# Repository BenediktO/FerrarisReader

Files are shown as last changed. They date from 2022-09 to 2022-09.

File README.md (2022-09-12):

# Ferraris Reader

This repo contains the files of the FerrarisReader project - A tool to read back power consumption of an old-school Ferraris meter.

## Physical setup

The sensor consists of an IR LED and a matching IR fototransistor or fotodiode, mounted such that the red marking on the turning wheel reduce the transmitted light effectively.
A holding structure is provided in `Objects/FerrarisHolder.stl` ready to slice.
It is designed to hold a 5mm LED and a 3mm fototransistor.
Edit `Objects/FerrarisHolder.scad` to fit the design to your need and use [openscad](https://openscad.org/) to convert to a slice-able file.
It is designed such that the point where the reflection occurs in a distance of 9mm. This can be changed by modifiying the distance between LED and sensor.
The schematic is shown below:

schematic

You only need the LED, sensor pair, a few resistors and a transistor (which is not really needed) together with an Arduino.
The Arduino needs to have a Serial interface, native or not or via FTDI does not really matter. You might, however need to change the Serial Port.
One pin of the arduino is reserved for the IR LED(s), in case you have more than one meter you want to read out, simply connect more IR LEDs in serial or parallel to the transistor. If you connect them in series, you need to lower the resistor value.
If you use a fotodiode instead of a fototransistor, you might need to increase the resistor to account for the reduced current.

Put the LED and the sensor into the 3D printed holder and connect wires to each of the pins.
On the other end of the wires create the above-shown circuit, test the LED polarity using a multimeter in diode-mode and the photo sensor in resistor mode.

In case you want some visual feedback, connect an LED to a spare pin using an appropriate resistor.
You can also use the builtin LED (13).

## Arduino sketch

You might need to modify the Arduino sketch.

- Specify the IR LED pin, there is only one even though many sensors are connected.
- Specify the number of sensors
- Specify their pin numbers. Important: All those have to be analog pins (`A0`, `A1`, ...)
- Optional: Specify the pins of the activity LED

## Experimenting with the settings

Connect the sensor(s) to the meter by using a bit of tape. Make sure that the sensor is properly aligned.
This can be done by enabling `ALIGNMENT_MODE` in the Arduino Sketch and observing the results in the serial monitor or serial plotter.
The dips in reflectivity should be as clearly visible as possible.

## SCPI Interface

The device follows the SCPI standard, a well-established text-based protocol to communicate with laboratory equipment.

The following commands are supported:

- `*IDN?`: returns the identification string
- `*RST`: resets the device
- `MEASure`
  - `:TICKs`
    - `?`: returns the number of ticks received
    - `:SET [CHANNEL = 0,]<VALUE>`: used to preset the tick counter
    - `:PERiod? [CHANNEL = 0]`: returns the revolution time of the last turn
    - `:LAST? [CHANNEL = 0]`: returns the time since the last tick
  - `:SENSor`
    - `:DARK? [CHANNEL = 0]`: returns the dark current (IR LED off)
    - `:ACTIve? [CHANNEL = 0]`: returns the active current (IR LED on)
    - `:EFFEctive? [CHANNEL = 0]`: returns the difference active - dark current
    - `:SNR? [CHANNEL = 0]`: returns a quantity from 0 - 1, representing the quality, 1 is best.

- `CALCulate`
  - `:ENERgy? [CHANNEL = 0]`: returns the calculated energy
  - `:POWer? [CHANNEL = 0]`: returns the calculated power, which is the average power of the last revolution

- `CONFigure`
  - `:SENSor`
    - `:THREshold`
      - `:UPPer [CHANNEL = 0,]<THRESHOLD>`: sets the upper threshold of a channel
      - `:UPPer? [CHANNEL = 0]`: returns the upper threshold of a channel
      - `:LOWer [CHANNEL = 0,]<THRESHOLD>`: sets the lower threshold of a channel
      - `:LOWer? [CHANNEL = 0]`: returns the lower threshold of a channel
    - `:DURation [CHANNEL = 0,]<DURATION>`: sets the minimum duration of the pulse
    - `:DURation? [CHANNEL = 0]`: returns the minimum duration of the pulse

- `SYSTem`
  - `:CHANnels?`: returns the number of channels of the device
  - `:FREQuency?`: returns the sampling frequency of the last second

Explanation:

This tree represents all possible commands. To assemble a command, join the strings on the branches.
I.e. to set the upper threshold of sensor 1 to 200, use:

`CONFigure:SENSor:THREshold:UPPer 1,200`

The upper case parts of the tokens are required, the lower case part can be omitted.
Note that the command is case-insensitive.
The following commands are equivalent:

```SCPI
CONFigure:SENSor:THREshold:UPPer 1,200
CONF:SENS:THRE:UPP 1,200
conf:sens:thre:upp 1,200
```

Values in brackets `[]` are optional, the default for `CHANNEL` is always 0.
Values in `<>` are required. Parameters are separated by `,`, commands can be joined using `;`.
Queries which return an answer are terminated with a `?`.

## Python scripts

### logger.py

To read back the data from a PC or raspberry, use the provided python script.
It needs the additional package `pyserial`, which can be installed using pip.
Use `python3 logger.py --help` for a reference how to use the program.

### plot.py

To plot the captured data, the script `analyze/plot.py` can be used.
It needs the additional packages `numpy` and `matplotlib`.
Use `python3 plot.py --help` for a reference how to use the program.

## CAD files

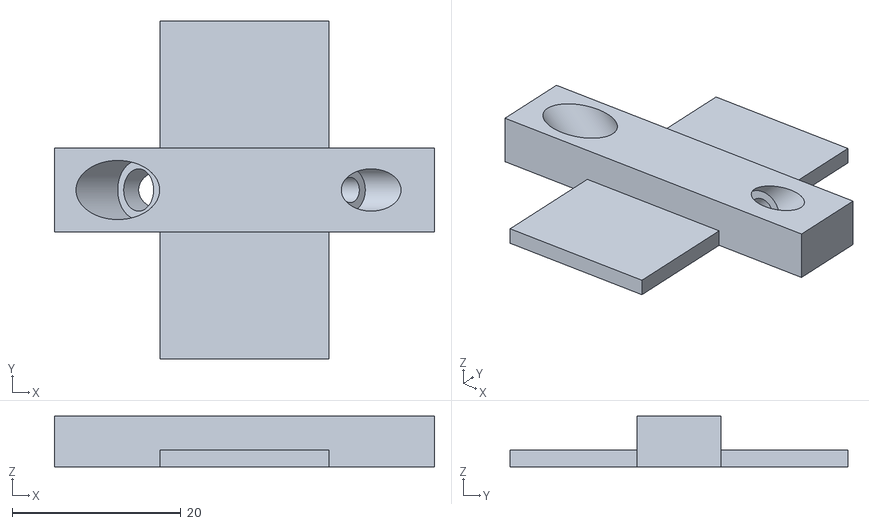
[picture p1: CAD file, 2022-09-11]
Objects/FerrarisHolder.stl
45.0 x 40.0 x 6.00

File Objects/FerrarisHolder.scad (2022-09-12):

$fn = 100;

LED_DIAMETER = 5;       // in mm
SENSOR_DIAMETER = 3;    // in mm
SENSOR_DISTANCE = 18;   // in mm

LENGTH = 45;            // in mm
WIDTH = 10;             // in mm
HEIGHT = 6;             // in mm

difference() {
    union() {
        translate([-LENGTH / 2, -WIDTH / 2])
            cube([LENGTH, WIDTH, HEIGHT]);
        translate([-10, -20])
            cube([20, 40, 2]);
    }
    translate([SENSOR_DISTANCE / 2, 0])
        rotate([0, 45, 0])
        union(){
            translate([0, 0, -100])
                cylinder(h=200, r=SENSOR_DIAMETER / 2);  // IR fototransistor
            translate([0, 0, 5])
                cylinder(h=100, r=SENSOR_DIAMETER / 2 + 1);
        }

    translate([-SENSOR_DISTANCE / 2, 0])
        rotate([0, -45, 0])
        union(){
            translate([0, 0, -100])
                cylinder(h=200, r=LED_DIAMETER / 2);  // IR fototransistor
            translate([0, 0, 5])
                cylinder(h=100, r=LED_DIAMETER / 2 + 1);
        }
}

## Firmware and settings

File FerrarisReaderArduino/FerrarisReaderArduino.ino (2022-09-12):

// FerrarisReader - A tool to read old school ferraris energy meters
//
// Copyright (C) 2022  Benedikt Otto <otto@hiskp.uni-bonn.de>
//
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


#include "Arduino.h"

#include <ctype.h>

#include "Vrekrer_scpi_parser.h"

//#define DEBUG

SCPI_Parser controller;


// Serial port to use
#define SERIAL Serial

// Number of sensors
#define NUM_CHANNELS 2

// Pin where the LED (via transistor) is connected to
#define IR_LEDS 9
// Pins for the sensors
int IR_SENSORS[NUM_CHANNELS] = {A0, A1};

// Pin where the activity LED is connected to, comment to deactivate
#define ACTIVITY_LED_PIN 10

// default values
#define DEFAULT_UPPER_THRESHOLD 100
#define DEFAULT_LOWER_THRESHOLD 50
#define DEFAULT_DURATION 20

// meter setup
#define TURNS_PER_KWH 75
#define KWH_PER_TURN (1.0 / TURNS_PER_KWH)

// target samplingrate
#define SAMPLINGRATE 250

// For aligning the sensor, uncomment the following line:
//#define ALIGNMENT_MODE



// Do not touch

#ifdef ALIGNMENT_MODE
  #define ALIGNMENT_PIN A0
#endif


#ifdef ACTIVITY_LED_PIN
  #define ACTIVITY_LED_ON digitalWrite(ACTIVITY_LED_PIN, HIGH);
  #define ACTIVITY_LED_OFF digitalWrite(ACTIVITY_LED_PIN, LOW);
#else
  #define ACTIVITY_LED_ON
  #define ACTIVITY_LED_OFF
#endif


bool readout_state = false;
uint8_t second_counter = 0;
uint16_t livetime_counter = 0;
uint16_t livetime_counter_buf = 0;

unsigned long time;
unsigned long last_time;
unsigned long last_time_seconds;


// structure holding the sensor data and parameters
struct SensorData
{
  uint16_t active_value;
  uint16_t dark_value;
  int high_counter;
  int low_counter;
  bool state;
  uint32_t ticks;
  uint32_t last_tick;
  uint32_t second_last_tick;
  uint16_t upper_threshold;
  uint16_t lower_threshold;
  uint16_t duration;
};


struct SensorData sensors[NUM_CHANNELS];


////////////////////////////////////////////////////////////////////////////////
//                                   tools                                    //
////////////////////////////////////////////////////////////////////////////////


// Extracts the channel number from the SCPI parameters, channel is always the first
int get_channel_number(SCPI_P parameters) {
  if (parameters.Size() < 1)
    return 0;
  int temp = String(parameters[0]).toInt();
  // basic validation
  if ((0 <= temp) && (temp < NUM_CHANNELS))
    return temp;
  return 0;
}

// Reset all sensor structs
void reset(void) {
  struct SensorData * sensor;
  for (int i=0; i<NUM_CHANNELS; i++) {
    sensor = &sensors[i];
    sensor->ticks = 0;
    sensor->high_counter = 0;
    sensor->low_counter = 0;
    sensor->state = true;
    sensor->upper_threshold = DEFAULT_UPPER_THRESHOLD;
    sensor->lower_threshold = DEFAULT_LOWER_THRESHOLD;
    sensor->duration = DEFAULT_DURATION;
  }
}

// Returns char array with lower case
char *toLower(char *str, size_t len)
{
    char *str_l = calloc(len + 1, sizeof(char));

    for (size_t i = 0; i < len; ++i) {
        str_l[i] = tolower((unsigned char)str[i]);
    }
    return str_l;
}


////////////////////////////////////////////////////////////////////////////////
//                           SCPI standard commands                           //
////////////////////////////////////////////////////////////////////////////////


// Returns the identication string
void Identify(SCPI_C commands, SCPI_P parameters, Stream& interface) {
  ACTIVITY_LED_ON
  interface.println(F("Arduino, FerrarisReader, V1.0, V1.0"));
  ACTIVITY_LED_OFF
}

// Resets the Controller Board
void Reset(SCPI_C commands, SCPI_P parameters, Stream& interface) {
  ACTIVITY_LED_ON
  reset();
  ACTIVITY_LED_OFF
}

// Returns the number of ticks (turns) detected
void MeasureTicks(SCPI_C commands, SCPI_P parameters, Stream& interface) {
  ACTIVITY_LED_ON
  struct SensorData sensor = sensors[get_channel_number(parameters)];
  interface.println(sensor.ticks);
  ACTIVITY_LED_OFF
}

// Presets the number of ticks
void SetTicks(SCPI_C commands, SCPI_P parameters, Stream& interface) {
  ACTIVITY_LED_ON
  struct SensorData * sensor;
  if (parameters.Size() >= 1) {
    if (parameters.Size() >= 2) {
      sensor = &sensors[get_channel_number(parameters)];
      sensor->ticks = String(parameters[1]).toInt();
    }
    else {
      sensor = &sensors[0];
      sensor->ticks = String(parameters[0]).toInt();
    }
  }
  ACTIVITY_LED_OFF
}

// Returns the dark current in ADC channels
void MeasureDark(SCPI_C commands, SCPI_P parameters, Stream& interface) {
  ACTIVITY_LED_ON
  struct SensorData sensor = sensors[get_channel_number(parameters)];
  interface.println(sensor.dark_value);
  ACTIVITY_LED_OFF
}

// Returns the active current in ADC channels
void MeasureActive(SCPI_C commands, SCPI_P parameters, Stream& interface) {
  ACTIVITY_LED_ON
  struct SensorData sensor = sensors[get_channel_number(parameters)];
  interface.println(sensor.active_value);
  ACTIVITY_LED_OFF
}

// Returns the difference of active and dark current in ADC channels 
void MeasureEffective(SCPI_C commands, SCPI_P parameters, Stream& interface) {
  ACTIVITY_LED_ON
  struct SensorData sensor = sensors[get_channel_number(parameters)];
  interface.println(sensor.active_value - sensor.dark_value);
  ACTIVITY_LED_OFF
}

// Returns a quantity from 0 to 1 representing the quality of the signal
void MeasureSNR(SCPI_C commands, SCPI_P parameters, Stream& interface) {
  ACTIVITY_LED_ON
  struct SensorData sensor = sensors[get_channel_number(parameters)];
  interface.println(1 - (float) sensor.dark_value / sensor.active_value);
  ACTIVITY_LED_OFF
}

// Returns the amount of energy measured
void MeasureEnergy(SCPI_C commands, SCPI_P parameters, Stream& interface) {
  ACTIVITY_LED_ON
  struct SensorData sensor = sensors[get_channel_number(parameters)];
  interface.println(((float) sensor.ticks) / TURNS_PER_KWH);
  ACTIVITY_LED_OFF
}

// Returns the power measured during the last revolution
void MeasurePower(SCPI_C commands, SCPI_P parameters, Stream& interface) {
  ACTIVITY_LED_ON
  struct SensorData sensor = sensors[get_channel_number(parameters)];
  if (sensor.ticks < 2)
    interface.println(F("Invalid"));
  else {
    interface.println(KWH_PER_TURN * 3600000.0 / (sensor.last_tick - sensor.second_last_tick), 4);
  }
  ACTIVITY_LED_OFF
}

// Returns the duration of the last revolution
void MeasurePeriod(SCPI_C commands, SCPI_P parameters, Stream& interface) {
  ACTIVITY_LED_ON
  struct SensorData sensor = sensors[get_channel_number(parameters)];
  if (sensor.ticks < 2)
    interface.println(F("Invalid"));
  else {
    interface.println((sensor.last_tick - sensor.second_last_tick) / 1000.0);
  }
  ACTIVITY_LED_OFF
}

// Returns the time that has elapsed since the last tick
void MeasureLastTick(SCPI_C commands, SCPI_P parameters, Stream& interface) {
  ACTIVITY_LED_ON
  struct SensorData sensor = sensors[get_channel_number(parameters)];
  if (sensor.ticks < 1)
    interface.println(F("Invalid"));
  else
    interface.println((millis() - sensor.last_tick) / 1000.0);
  ACTIVITY_LED_OFF
}

// Sets the parameters upper and lower threshold
void ConfSetThreshold(SCPI_C commands, SCPI_P parameters, Stream& interface) {
  ACTIVITY_LED_ON
  struct SensorData * sensor;
  uint16_t value;
  if (parameters.Size() >= 1) {
    if (parameters.Size() >= 2) {
      sensor = &sensors[get_channel_number(parameters)];
      value = String(parameters[1]).toInt();
    }
    else {
      sensor = &sensors[0];
      value = String(parameters[0]).toInt();
    }
  if (strcmp(toLower(commands[3], 3), "upp") == 0)
    sensor->upper_threshold = value;
  else if (strcmp(toLower(commands[3], 3), "low") == 0)
    sensor->lower_threshold = value;
  }
  ACTIVITY_LED_OFF
}

// Returns the parameters upper and lower threshold
void ConfGetThreshold(SCPI_C commands, SCPI_P parameters, Stream& interface) {
  ACTIVITY_LED_ON
  struct SensorData sensor = sensors[get_channel_number(parameters)];
  if (strcmp(toLower(commands[3], 3), "upp") == 0)
    interface.println(sensor.upper_threshold);
  else if (strcmp(toLower(commands[3], 3), "low") == 0)
    interface.println(sensor.lower_threshold);
  ACTIVITY_LED_OFF
}

// Sets the parameter duration
void ConfSetDuration(SCPI_C commands, SCPI_P parameters, Stream& interface) {
  ACTIVITY_LED_ON
  struct SensorData * sensor;
  if (parameters.Size() >= 1) {
    if (parameters.Size() >= 2) {
      sensor = &sensors[get_channel_number(parameters)];
      sensor->duration = String(parameters[1]).toInt();
    }
    else {
      sensor = &sensors[0];
      sensor->duration = String(parameters[0]).toInt();
    }
  }
  ACTIVITY_LED_OFF
}

// Returns the parameter duration
void ConfGetDuration(SCPI_C commands, SCPI_P parameters, Stream& interface) {
  ACTIVITY_LED_ON
  struct SensorData sensor = sensors[get_channel_number(parameters)];
  interface.println(sensor.duration);
  ACTIVITY_LED_OFF
}

// Returns the number of channels of the device
void CountChannels(SCPI_C commands, SCPI_P parameters, Stream& interface) {
  ACTIVITY_LED_ON
  interface.println(NUM_CHANNELS);
  ACTIVITY_LED_OFF
}

// Returns the number of samples during the last second
void GetFrequency(SCPI_C commands, SCPI_P parameters, Stream& interface) {
  ACTIVITY_LED_ON
  interface.println(livetime_counter_buf);
  ACTIVITY_LED_OFF
}

// One tick has occurred, update data.
void tick(struct SensorData * sensor_data) {
  sensor_data->ticks++;
  sensor_data->second_last_tick = sensor_data->last_tick;
  sensor_data->last_tick = millis();
}

// Handle a new pair of active/dark measurement
void handle_measurement(struct SensorData * sensor_data) {
  int difference = sensor_data->active_value - sensor_data->dark_value;

  if (difference > sensor_data->upper_threshold) {
    sensor_data->high_counter++;
    if (sensor_data->high_counter > sensor_data->duration) {
      if (!sensor_data->state)
          tick(sensor_data);    // active -> inactive transition
      sensor_data->state = true;
    }
  }
  else {
    sensor_data->high_counter = 0;
    if (difference < sensor_data->lower_threshold) {
      sensor_data->low_counter++;
      if (sensor_data->low_counter > sensor_data->duration)
        sensor_data->state = false;
    }
    else {
      sensor_data->low_counter = 0;
    }
  }
}



void setup() {
  // SCPI standard commands
  controller.RegisterCommand(F("*IDN?"), &Identify);
  controller.RegisterCommand(F("*RST"), &Reset);

  // MEASure commands
  controller.RegisterCommand(F("MEASure:TICKs?"), &MeasureTicks);
  controller.RegisterCommand(F("MEASure:TICKs:SET"), &SetTicks);
  controller.RegisterCommand(F("MEASure:SENSor:DARK?"), &MeasureDark);
  controller.RegisterCommand(F("MEASure:SENSor:ACTIve?"), &MeasureActive);
  controller.RegisterCommand(F("MEASure:SENSor:EFFEctive?"), &MeasureEffective);
  controller.RegisterCommand(F("MEASure:SENSor:SNR?"), &MeasureSNR);
  controller.RegisterCommand(F("MEASure:TICKs:PERiod?"), &MeasurePeriod);
  controller.RegisterCommand(F("MEASure:TICKs:LAST?"), &MeasureLastTick);

  // CALCulate commands
  controller.RegisterCommand(F("CALCulate:ENERgy?"), &MeasureEnergy);
  controller.RegisterCommand(F("CALCulate:POWer?"), &MeasurePower);

  // CONFigure commands
  controller.RegisterCommand(F("CONFigure:SENSor:THREshold:UPPer"), &ConfSetThreshold);
  controller.RegisterCommand(F("CONFigure:SENSor:THREshold:LOWer"), &ConfSetThreshold);
  controller.RegisterCommand(F("CONFigure:SENSor:THREshold:UPPer?"), &ConfGetThreshold);
  controller.RegisterCommand(F("CONFigure:SENSor:THREshold:LOWer?"), &ConfGetThreshold);
  controller.RegisterCommand(F("CONFigure:SENSor:DURation"), &ConfSetDuration);
  controller.RegisterCommand(F("CONFigure:SENSor:DURation?"), &ConfGetDuration);

  // SYSTem commands
  controller.RegisterCommand(F("SYSTem:CHANnels?"), &CountChannels);
  controller.RegisterCommand(F("SYSTem:FREQuency?"), &GetFrequency);

  reset();

  SERIAL.begin(9600);
  // Wait until serial connection is established
  while (!SERIAL) {;}

  #ifdef ACTIVITY_LED_PIN
    pinMode(ACTIVITY_LED_PIN, OUTPUT);
  #endif

  pinMode(IR_LEDS, OUTPUT);
  for (int i=0; i < NUM_CHANNELS; i++)
    pinMode(IR_SENSORS[i], INPUT);


  // switch off LEDs
  #ifdef LED_BUILTIN_TX
    pinMode(LED_BUILTIN_TX, INPUT);
  #endif
  #ifdef LED_BUILTIN_RX
    pinMode(LED_BUILTIN_RX, INPUT);
  #endif


  #ifdef DEBUG
    delay(2000);
    controller.PrintDebugInfo();
  #endif
}



void loop()
{

  #ifdef ALIGNMENT_MODE
    SERIAL.println(analogRead(ALIGNMENT_PIN));
    delay(100);
  #else
    // Let SCPI parser do its thing
    controller.ProcessInput(SERIAL, "\n");


    time = millis();
    // execute roughly  SAMPLINGRATE-times per second
    if ((time - last_time) >= (500 / SAMPLINGRATE)) {
      last_time = time;
      if (readout_state) {
        for (int i=0; i < NUM_CHANNELS; i++) {
          sensors[i].dark_value = analogRead(IR_SENSORS[i]);  // First step: measure dark current
        }
        digitalWrite(IR_LEDS, HIGH);   // First step: switch on LEDs
        break;
      }
      else {
        for (int i=0; i < NUM_CHANNELS; i++) {
          sensors[i].active_value = analogRead(IR_SENSORS[i]);  // Second step: measure active current and evaluate
          handle_measurement(&sensors[i]);
        }
        livetime_counter++;
        digitalWrite(IR_LEDS, LOW);   // Thirds step: switch off LEDs
        break;
      }
      readout_state = !readout_state;
    }

    // Every second, store and reset livetime_counter
    if ((time - last_time_seconds) >= 1000) {
      last_time_seconds = time;
      livetime_counter_buf = livetime_counter;
      livetime_counter = 0;
    }
  #endif
}

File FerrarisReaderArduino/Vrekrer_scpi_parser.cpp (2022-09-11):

#include "Vrekrer_scpi_parser.h"

// ## SCPI_String_Array member functions ##

///Add indexing capability.
char* SCPI_String_Array::operator[](const uint8_t index) {
  return values_[index];
}

///Append new string (LIFO stack Push).
void SCPI_String_Array::Append(char* value) {
  if (size_ < storage_size) {
    values_[size_] = value;
    size_++;
  }
}

///LIFO stack Pop
char* SCPI_String_Array::Pop() {
  if (size_ > 0) {
    size_--;
    return values_[size_];
  } else {
    return NULL;
  }
}

///Returns the first element of the array
char* SCPI_String_Array::First() {
  if (size_ > 0) {
    return values_[0];
  } else {
    return NULL;
  }
}

///Returns the last element of the array
char* SCPI_String_Array::Last() {
  if (size_ > 0) {
    return values_[size_ - 1];
  } else {
    return NULL;
  }
}

///Array size
uint8_t SCPI_String_Array::Size() {
  return size_;
}


// ## SCPI_Commands member functions ##

///Dummy constructor.
SCPI_Commands::SCPI_Commands(){}

/*!
 Constructor that extracts and tokenize a command from a message.  
 @param message  Message to process.

 The message is processed until a space, tab or the end of the string is 
 found, the rest is available at not_processed_message.  
 The processed part is split on the ':' characters, the resulting parts 
 (tokens) are stored in the array.
*/
SCPI_Commands::SCPI_Commands(char* message) {
  char* token = message;
  // Trim leading spaces and tabs
  while (isspace(*token)) token++;
  // Save parameters and multicommands for later
  not_processed_message = strpbrk(token, " \t");
  if (not_processed_message != NULL) {
   not_processed_message[0] = '\0';
   not_processed_message++;
  }
  // Split using ':'
  token = strtok(token, ":");
  while (token != NULL) {
    this->Append(token);
    token = strtok(NULL, ":");
  }
}


// ## SCPI_Parameters member functions ##

/// Dummy constructor.
SCPI_Parameters::SCPI_Parameters(){}


/*!
 Constructor that extracts and splits parameters from a message.  
 @param message[in,out]  Message to process.

 The message is split on the ',' characters, the resulting parts 
 (parameters) are stored in the array after trimming any start spaces.
*/
SCPI_Parameters::SCPI_Parameters(char* message) {
  char* parameter = message;
  // Split using ','
  parameter = strtok(parameter, ",");
  while (parameter != NULL) {
    while(isspace(*parameter)) parameter++;
    this->Append(parameter);
    parameter = strtok(NULL, ",");
  }
  //TODO add support for strings parameters (do not split parameters inside "")
}

//Do nothing function
void DefaultErrorHandler(SCPI_C c, SCPI_P p, Stream& interface) {}


// ## SCPI_Registered_Commands member functions. ##

SCPI_Default_Config scpi_default_config;

/*!
 SCPI_Parser constructor.

 Example:  
  ``SCPI_Parser my_instrument``;
*/
SCPI_Parser::SCPI_Parser(){
  msg_buffer_ = scpi_default_config.message_buffer;
  buffer_length = 64;
  callers_[max_commands] = &DefaultErrorHandler;
}

/*!
 SCPI_Parser customizable constructor.

 Example:  
  ``mesage_buffer = SCPI_Message_Buffer<64>();``
  ``SCPI_Parser my_instrument();``
  ``
*/
SCPI_Parser::SCPI_Parser(SCPI_Message_Buffer_ABC mesage_buffer){
  msg_buffer_ = mesage_buffer.data;
  buffer_length = mesage_buffer.size;
  callers_[max_commands] = &DefaultErrorHandler;
}

///Add a token to the tokens' storage
void SCPI_Parser::AddToken_(char *token) {
  size_t token_size = strlen(token);
  bool isQuery = (token[token_size - 1] == '?');
  if (isQuery) token_size--;

  bool allready_added = false;
  for (uint8_t i = 0; i < tokens_size_; i++)
    allready_added ^= (strncmp(token, tokens_[i], token_size) == 0);
  if (!allready_added) {
    if (tokens_size_ < max_tokens) {
      char *stored_token = new char [token_size + 1];
      strncpy(stored_token, token, token_size);
      stored_token[token_size] = '\0';
      tokens_[tokens_size_] = stored_token;
      tokens_size_++;
    }
  }
}

/*!
 Get a hash from a valid command
 @param commands  Keywords of a command
 @return hash

 Return 0 if the command contains keywords not registered as tokens.  
 The hash is calculated including the TreeBase hash.  
 @see SetCommandTreeBase
*/
scpi_hash_t SCPI_Parser::GetCommandCode_(SCPI_Commands& commands) {
  scpi_hash_t code;
  if (tree_code_) {
    code = tree_code_;
  } else {
    code = 7; //Magic hash offset
  }
  bool isQuery = false;

  //Loop all keywords in the command
  for (uint8_t i = 0; i < commands.Size(); i++) {
    //Get keywords's length
    size_t header_length = strlen(commands[i]);
    
    //For the last keywords test if it is a query
    //and remove '?' from the keywords's length if needed.
    if (i == commands.Size() - 1) {
      isQuery = (commands[i][header_length - 1] == '?');
      if (isQuery) header_length--;
    }

    bool isToken;
    for (uint8_t j = 0; j < tokens_size_; j++) {
      //Get the token's short and long lengths
      size_t short_length = 0;
      while (isupper(tokens_[j][short_length])) short_length++;
      size_t long_length = strlen(tokens_[j]);

      //If the token allows numeric suffixes
      //remove the trailing digits from the header
      if ( (tokens_[j][long_length - 1] == '#')
         && (commands[i][header_length - 1] != '#') ) {
        long_length--;
        while (isdigit(commands[i][header_length - 1])) header_length--;
      }

      //Test if the header match with the token
      isToken = true;
      if (header_length == short_length) {
        for (uint8_t k  = 0; k < short_length; k++)
          isToken &= (toupper(commands[i][k]) == tokens_[j][k]);
      } else if (header_length == long_length) {
        for (uint8_t k  = 0; k < long_length; k++)
          isToken &= (toupper(commands[i][k]) == toupper(tokens_[j][k]));
      } else {
        isToken = false;
      }

      //We use the token number j for hashing
      //hash(i) = hash(i - 1) * hash_magic_number + j
      if (isToken) {
        code *= hash_magic_number;
        code += j;
        break;
      }
    }
    if (!isToken) return 255;
  }
  if (isQuery) {
    code *= 37;
    code -= 1;
  }
  return code;
}

/*!
 Change the TreeBase for the next RegisterCommand calls.
 @param tree_base  TreeBase to be used.  
        An empty string ``""`` sets the TreeBase to root.
*/
void SCPI_Parser::SetCommandTreeBase(char* tree_base) {
  if (strlen(tree_base) > 0) {
    SCPI_Commands tree_tokens(tree_base);
    for (uint8_t i = 0; i < tree_tokens.Size(); i++)
      AddToken_(tree_tokens[i]);
    tree_code_ = 0;
    tree_code_ = this->GetCommandCode_(tree_tokens);
  } else {
    tree_code_ = 0;
  }
}

/*!
 SetCommandTreeBase version with RAM string support.

 Example:  
 ``my_instrument.SetCommandTreeBase("SYSTem:LED");``  
 For lower RAM usage use the Flash strings version.
*/
void SCPI_Parser::SetCommandTreeBase(const char* tree_base) {
  strcpy(msg_buffer_, tree_base);
  this->SetCommandTreeBase(msg_buffer_);
}
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

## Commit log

2022-09-11 Add stuff
    [FerrarisHolder.scad, FerrarisHolder.stl]
2022-09-11 Enable multiple sensors
2022-09-11 Switch off RX/TX LEDs
2022-09-12 Add documentation
    [FerrarisHolder.scad]

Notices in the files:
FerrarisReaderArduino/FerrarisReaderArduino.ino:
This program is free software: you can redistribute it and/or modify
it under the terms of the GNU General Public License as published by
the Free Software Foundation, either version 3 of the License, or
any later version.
